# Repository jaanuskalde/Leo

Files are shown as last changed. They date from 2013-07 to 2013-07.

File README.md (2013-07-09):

Leo
===

Tech-thing Leo board. Arduino Leonardo clone.

Useful for data logging.

Features
--------
* Small size but 100% headers are the same
* Micro, mini or B USB
* All headers are servo headers
* With selectable voltages
* Micro SD card
* Real time clock onboard
* Analog referance for more precise logging
* External watchdog timer
* 5V or 3v3 selectable

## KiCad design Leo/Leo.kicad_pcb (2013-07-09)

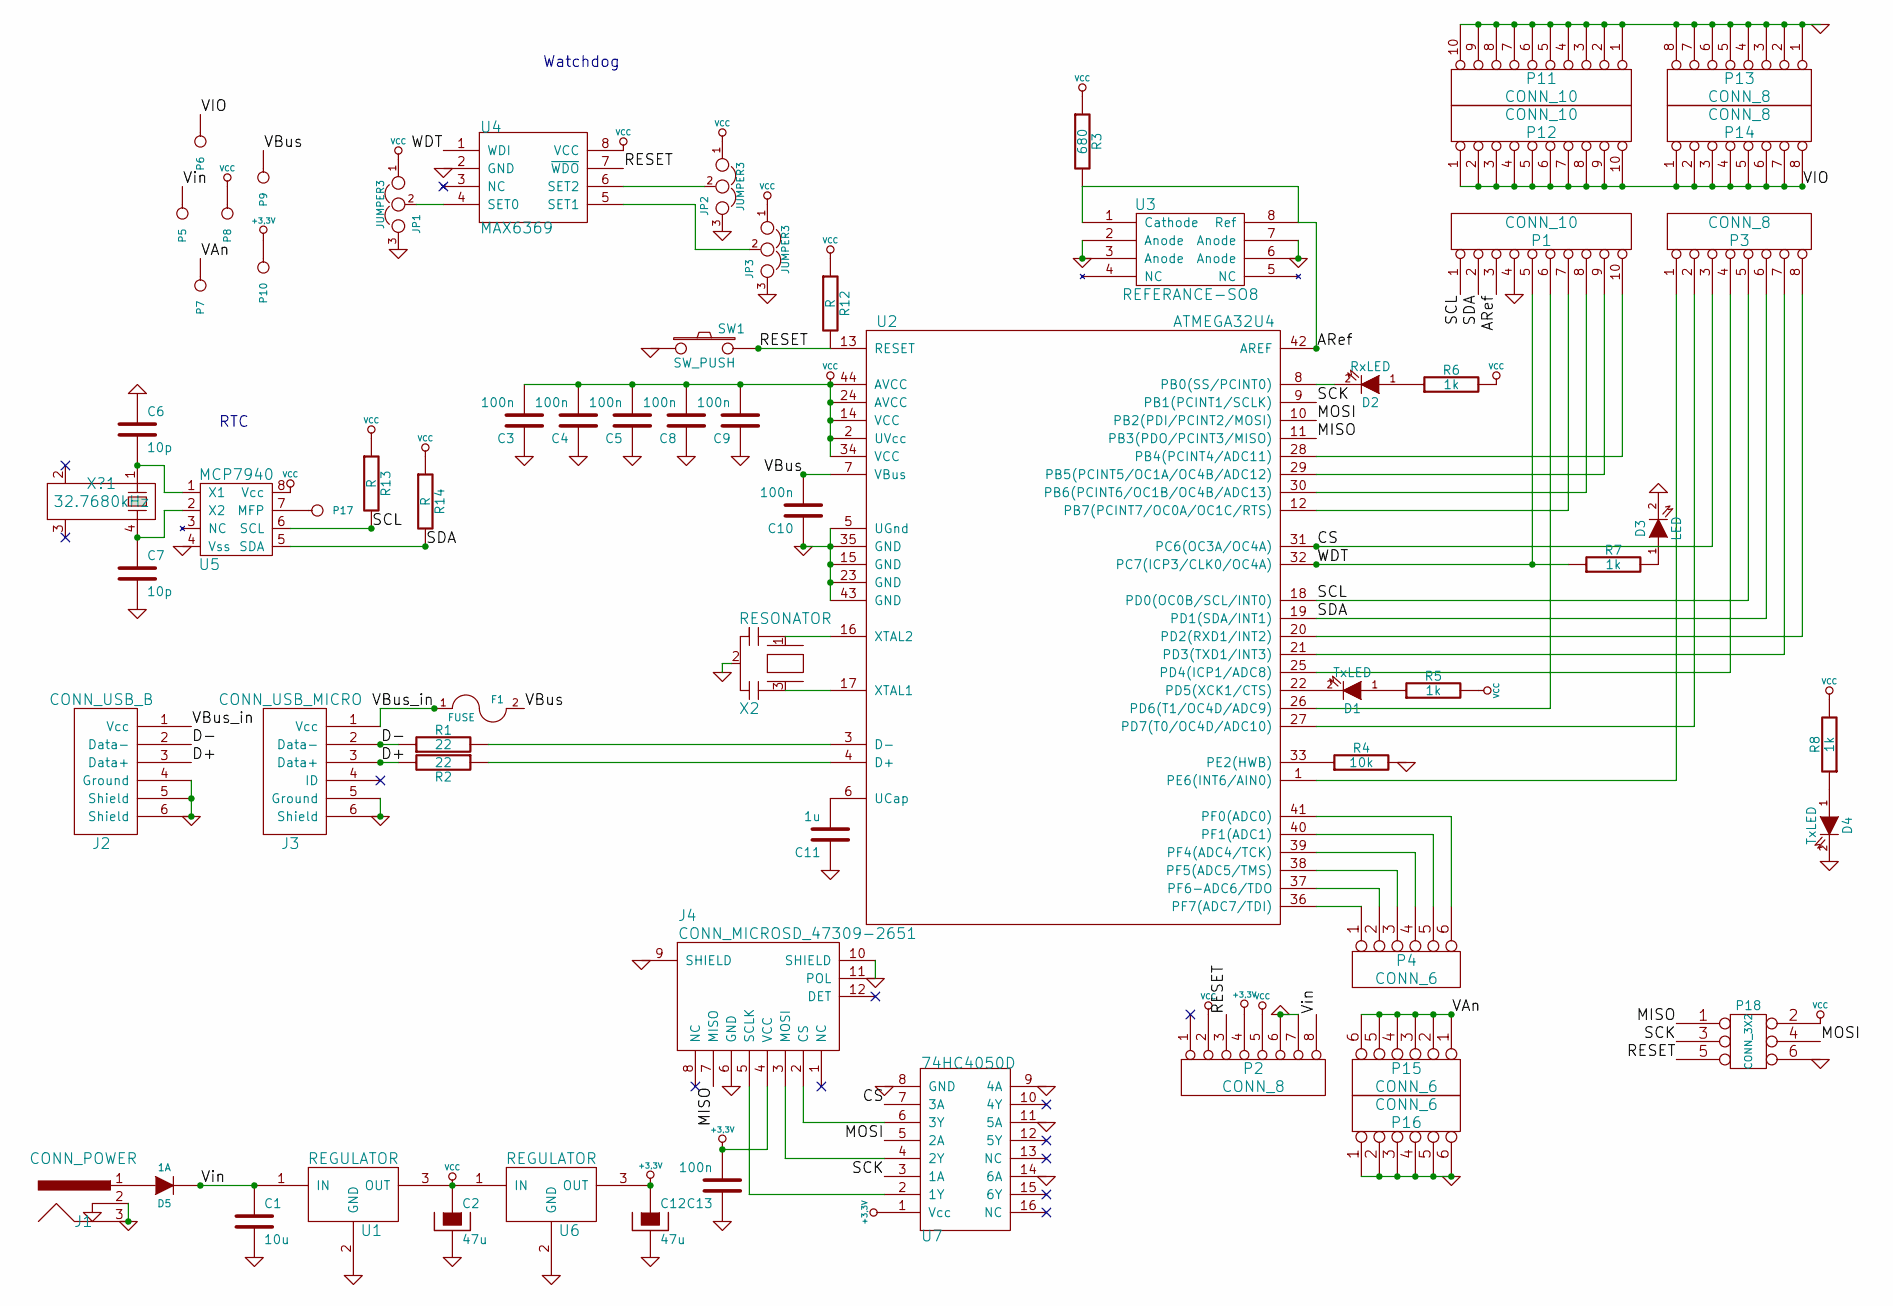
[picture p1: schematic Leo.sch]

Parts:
C1: 10u
C2, C12: 47u
C3, C4, C5, C8, C9, C10, C13: 100n
C6, C7: 10p
C11: 1u
D1, D4: TxLED
D2: RxLED
D3: LED
D5: 1A
F1: FUSE
J1: CONN_POWER
J2: CONN_USB_B
J3: CONN_USB_MICRO
J4: CONN_MICROSD_47309-2651
JP1, JP2, JP3: JUMPER3
P1: CONN_10
P2, P3: CONN_8
P4, P15, P16: CONN_6
P5, P6, P7, P8, P9, P10, P17: CONN_1
P11, P12: CONN_10
P13, P14: CONN_8
P18: CONN_3X2
R1, R2: 22
R3: 680
R4: 10k
R5, R6, R7, R8: 1k
R12, R13, R14: R
SW1: SW_PUSH
U1, U6: REGULATOR
U2: ATMEGA32U4
U3: REFERANCE-SO8
U4: MAX6369
U5: MCP7940
U7: 74HC4050D
X2: RESONATOR
X?1: 32.7680kHz

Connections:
+3.3V: C12.1, C13.2, J4.4 (VCC), P2.4, P10.1, U6.3 (OUT), U7.1 (Vcc)
/ARef: P1.3, R3.2, U2.42 (AREF), U3.1 (Cathode), U3.8 (Ref)
/CS: P3.3, U2.31 (PC6(OC3A/OC4A)), U7.7 (3A)
/D+: J2.3 (Data+), J3.3 (Data+), R2.2
/D-: J2.2 (Data-), J3.2 (Data-), R1.1
/MISO: J4.7 (MISO), P18.1, U2.11 (PB3(PDO/PCINT3/MISO))
/MOSI: P18.4, U2.10 (PB2(PDI/PCINT2/MOSI)), U7.5 (2A)
/RESET: P2.3, P18.5, R12.2, SW1.2, U2.13 (RESET), U4.7 (~WDO)
/SCK: P18.3, U2.9 (PB1(PCINT1/SCLK)), U7.3 (1A)
/SCL: P1.1, P3.5, R13.2, U2.18 (PD0(OC0B/SCL/INT0)), U5.6 (SCL)
/SDA: P1.2, P3.6, R14.2, U2.19 (PD1(SDA/INT1)), U5.5 (SDA)
/VAn: P7.1, P15.1, P15.2, P15.3, P15.4, P15.5, P15.6
/VBus: C10.2, F1.2, P9.1, U2.7 (VBus)
/VBus_in: F1.1, J2.1 (Vcc), J3.1 (Vcc)
/VIO: P6.1, P12.1, P12.2, P12.3, P12.4, P12.5, P12.6, P12.7, P12.8, P12.9, P12.10, P14.1, P14.2, P14.3, P14.4, P14.5, P14.6, P14.7, P14.8
/Vin: C1.1, D5.1 (K), P2.8, P5.1, U1.1 (IN)
/WDT: P1.5, R7.1, U2.32 (PC7(ICP3/CLK0/OC4A)), U4.1 (WDI)
GND: C1.2, C2.2, C3.1, C4.1, C5.1, C6.1, C7.2, C8.1, C9.1, C10.1, C11.1, C12.2, C13.1, D3.2 (K), D4.2 (K), J1.2, J1.3, J2.4 (Ground), J2.5 (Shield), J2.6 (Shield), J3.5 (Ground), J3.6 (Shield), J4.6 (GND), J4.9 (SHIELD), J4.10 (SHIELD), J4.11 (POL), JP1.3, JP2.3, JP3.3, P1.4, P2.6, P2.7, P11.1, P11.2, P11.3, P11.4, P11.5, P11.6, P11.7, P11.8, P11.9, P11.10, P13.1, P13.2, P13.3, P13.4, P13.5, P13.6, P13.7, P13.8, P16.1, P16.2, P16.3, P16.4, P16.5, P16.6, P18.6, R4.2, SW1.1, U1.2 (GND), U2.5 (UGnd), U2.15 (GND), U2.23 (GND), U2.35 (GND), U2.43 (GND), U3.2 (Anode), U3.3 (Anode), U3.6 (Anode), U3.7 (Anode), U4.2 (GND), U5.4 (Vss), U6.2 (GND), U7.8 (GND), U7.9 (4A), U7.11 (5A), U7.14 (6A), X2.2
unnamed: D4.1 (A), R8.1
unnamed: U2.16 (XTAL2), X2.1
unnamed: U2.17 (XTAL1), X2.3
unnamed: D3.1 (A), R7.2
unnamed: D1.1 (A), R5.1
unnamed: D1.2 (K), U2.22 (PD5(XCK1/CTS))
unnamed: C6.2, U5.1 (X1), X?1.1
unnamed: C7.1, U5.2 (X2), X?1.4
unnamed: P1.6, U2.26 (PD6(T1/OC4D/ADC9))
unnamed: P17.1, U5.7 (MFP)
unnamed: D2.2 (K), U2.8 (PB0(SS/PCINT0))
unnamed: D2.1 (A), R6.1
unnamed: P1.7, U2.12 (PB7(PCINT7/OC0A/OC1C/RTS))
unnamed: P1.10, U2.28 (PB4(PCINT4/ADC11))
unnamed: P1.9, U2.29 (PB5(PCINT5/OC1A/OC4B/ADC12))
unnamed: P1.8, U2.30 (PB6(PCINT6/OC1B/OC4B/ADC13))
unnamed: P4.6, U2.41 (PF0(ADC0))
unnamed: P4.1, U2.36 (PF7(ADC7/TDI))
unnamed: P4.2, U2.37 (PF6-ADC6/TDO)
unnamed: P4.3, U2.38 (PF5(ADC5/TMS))
unnamed: P4.4, U2.39 (PF4(ADC4/TCK))
unnamed: P4.5, U2.40 (PF1(ADC1))
unnamed: P3.1, U2.1 (PE6(INT6/AIN0))
unnamed: R4.1, U2.33 (PE2(HWB))
unnamed: P3.8, U2.20 (PD2(RXD1/INT2))
unnamed: P3.7, U2.21 (PD3(TXD1/INT3))
unnamed: P3.4, U2.25 (PD4(ICP1/ADC8))
unnamed: P3.2, U2.27 (PD7(T0/OC4D/ADC10))
unnamed: J4.2 (CS), U7.6 (3Y)
unnamed: J4.3 (MOSI), U7.4 (2Y)
unnamed: J4.5 (SCLK), U7.2 (1Y)
unnamed: D5.2 (A), J1.1
unnamed: JP2.2, U4.6 (SET2)
unnamed: JP3.2, U4.5 (SET1)
unnamed: JP1.2, U4.4 (SET0)
unnamed: R2.1, U2.4 (D+)
unnamed: R1.2, U2.3 (D-)
unnamed: C11.2, U2.6 (UCap)
VCC: C2.1, C3.2, C4.2, C5.2, C8.2, C9.2, JP1.1, JP2.1, JP3.1, P2.2, P2.5, P8.1, P18.2, R3.1, R5.2, R6.2, R8.2, R12.1, R13.1, R14.1, U1.3 (OUT), U2.2 (UVcc), U2.14 (VCC), U2.24 (AVCC), U2.34 (VCC), U2.44 (AVCC), U4.8 (VCC), U5.8 (Vcc), U6.1 (IN)

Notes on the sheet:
Watchdog
RTC

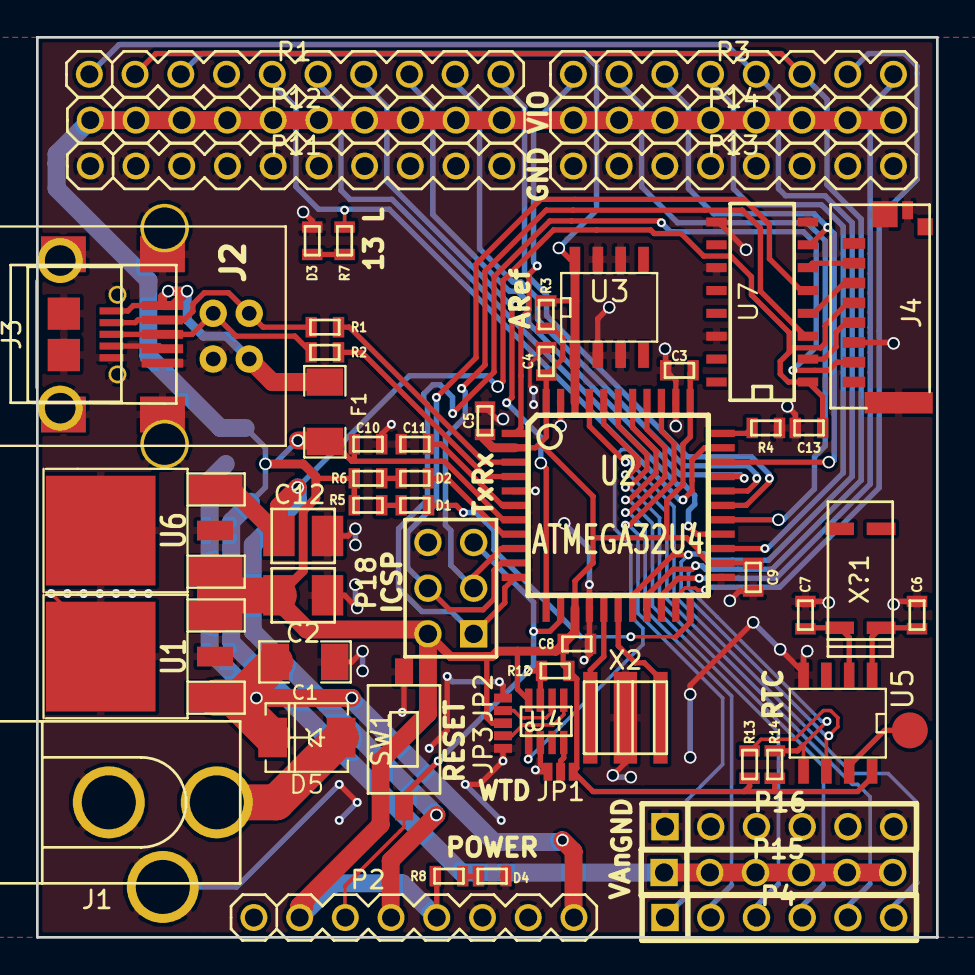
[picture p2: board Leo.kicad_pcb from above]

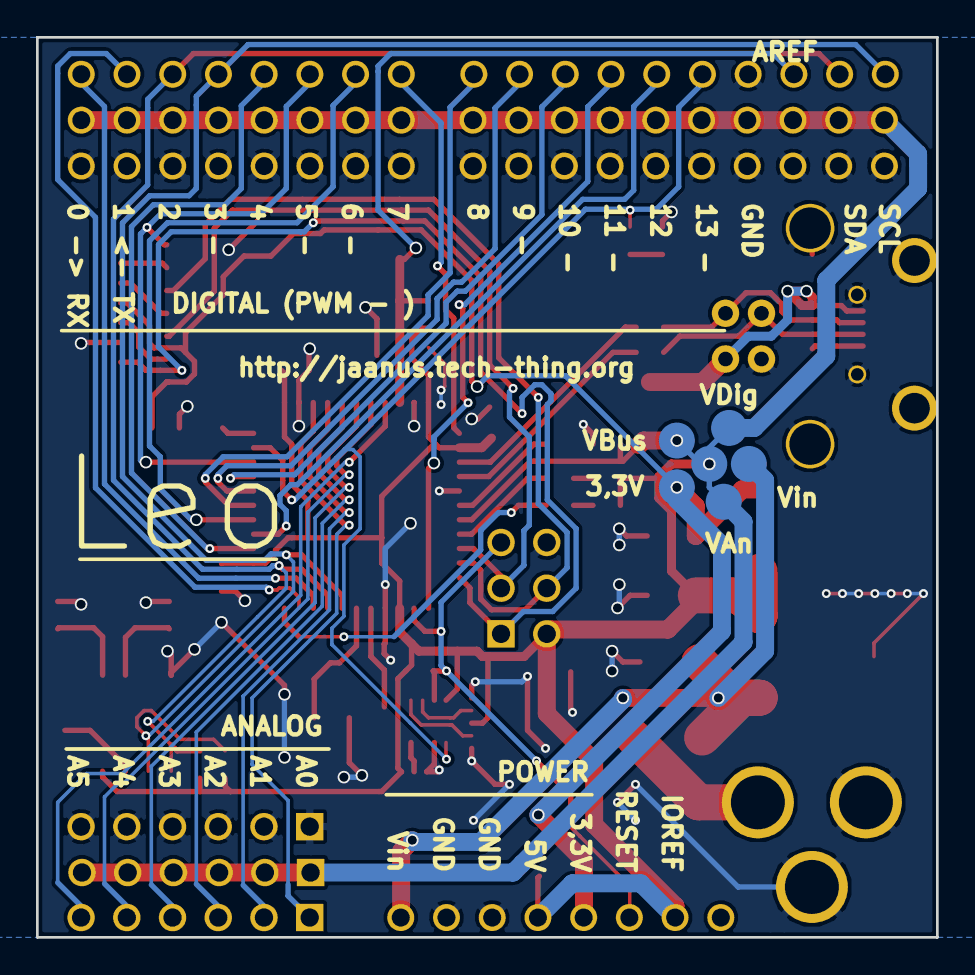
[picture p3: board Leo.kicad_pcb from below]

Board: 2 copper layers, 50.0 x 50.0 mm, 65 parts (6 on the bottom side), 57 nets.

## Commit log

2013-06-28 Version 1.0, first one to be manufactured, with some known bugs.
    [.kicad_pcb-B_Cu.gbl, .kicad_pcb-B_Mask.gbs, .kicad_pcb-B_SilkS.gbo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]
2013-07-09 Fixed MAX pinout, header spacing and silkscreen
    [Leo.kicad_pcb, Leo.sch]
